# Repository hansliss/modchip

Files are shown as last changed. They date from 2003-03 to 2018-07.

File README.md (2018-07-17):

# modchip
This a PCB design and ASM code for a Playstation modchip based on the tiny AVR AT90S1200.

Apart from the SSOP-20 chip, it uses two MicroMatch connectors (6-pin and 8-pin straight male through-hole mount), a Murata resonator, a LED, a capacitor and a pushbutton.

Note that everything except the MicroMatch connectors are mounted on the *rear* side!

The code wasn't properly version-tracked when I did this, so there are several different ASM files, of different age and for different uses. Figure it out!

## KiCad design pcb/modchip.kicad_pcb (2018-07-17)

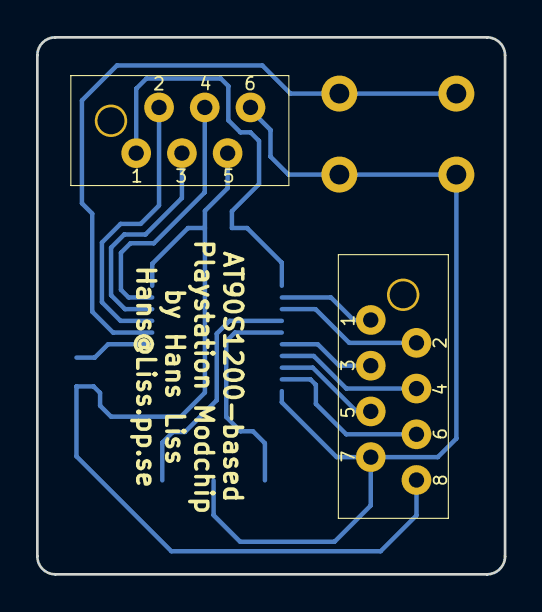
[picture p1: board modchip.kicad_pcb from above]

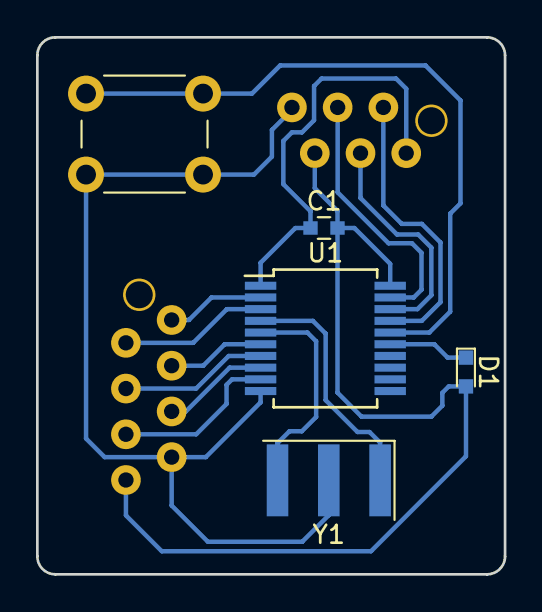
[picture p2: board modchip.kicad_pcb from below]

Board: 2 copper layers, 26.0 x 29.8 mm, 7 parts (5 on the bottom side), 16 nets.

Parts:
C1: C; C_0603
D1: LED; LED_0603
J1: Conn_02x04_Odd_Even; MicroMatch_FOB_TH_08P
J2: Conn_02x03_Odd_Even; MicroMatch_FOB_TH_06P
SW1: SW_Push; SW_PUSH_6mm
U1: AT90S1200-4YC; SSOP-20_5.3x7.2mm_Pitch0.65mm
Y1: Resonator; Resonator_SMD_muRata_SFECV-3pin_6.9x2.9mm

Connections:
GND: J1.7, J2.6, SW1.2, U1.10, Y1.2
unnamed: C1.1, J2.1, U1.1
unnamed: D1.1, U1.15
unnamed: J1.1, U1.2
unnamed: J1.2, U1.3
unnamed: J1.3, U1.6
unnamed: J1.4, U1.7
unnamed: J1.5, U1.8
unnamed: J1.6, U1.9
unnamed: J2.2, U1.17
unnamed: J2.3, U1.18
unnamed: J2.4, U1.19
unnamed: SW1.1, U1.16
unnamed: U1.4, Y1.1
unnamed: U1.5, Y1.3
VCC: C1.2, D1.2, J1.8, J2.5, U1.20

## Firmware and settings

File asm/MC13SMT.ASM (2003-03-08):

;***************************************************************************
;* Playstation Import enabler code
;* 
;* File Name            :modchip.asm
;* Title                :Playstation Import enabler code
;* Date                 :99-04-22
;* Version              :1.3
;* Support email        :Hans@Liss.pp.se
;* Target MCU           :AT90S1200
;* Clock type		:2MHz ceramic resonator or equiv.
;*
;* DESCRIPTION
;*
;* This code will send a Playstation region code (four characters - SCEE
;* for Europe, SCEI for Japan and SCEA for the US) as a serial bitstream
;* at about 250bps on an I/O pin, for a short time after RESET. It also
;* acts as a software jumper between two lines, and can handle blanking of
;* another signal. All these signals will go tristate after a certain time
;* to hide the chip. The processor will restart when the lid is opened and
;* closed and when the RESET switch is pressed and released.
;*
;* There is an option of connecting a pair of switches against GND to two
;* pins, and they can then be used to select between three different CNT
;* values, or disable the chip completely. The status of the switches is
;* read every time the sequence is to be started.
;*
;* A three-legged, dual-colour LED can be connected to two of the I/O pins
;* and GND.
;* It will then be used to show what the processor is doing - cycling
;* between colours when the code is being sent, turning green when it's
;* ready, turning red when disabled and yellow during a pending RESET or
;* media change.
;*
;*                       Processor chip layout
;*
;*	                      -----v-----
;*                         1 [|o        |] 20   Vcc
;*              Lid        2 [|         |] 19   
;*              Reset      3 [|         |] 18   
;*                         4 [|         |] 17   
;*                         5 [|         |] 16   Calibrate
;*              Blanking   6 [|         |] 15   LED
;*              Data OUT   7 [|         |] 14   
;*              Jumper IN  8 [|         |] 13   Switch 2
;*              Jumper OUT 9 [|         |] 12   Switch 1
;*              GND       10 [|         |] 11
;*                            -----------
;*
;*
;* This code is inspired by Scott Rider's widely distributed modchip code for
;* the PIC 12C508. The Atmel chip is far better at most of these things - 
;* many more registers and much more orthogonal instruction set along with
;* four times the speed of a comparable PIC. The AT90S1200 is, however, more
;* expensive than the 12C508, but OTOH it has lots more I/O pins,
;* making all these bells and whistles possible. And programming it is fun!
;* I am working with Atmels own "wavrasm" which as far as I know is 
;* available on their home page on <http://www.atmel.com>.
;*
;* Going back to Scott Rider, we can define a mapping between the pin
;* connections for his code, which appears to be the same for most of the
;* commercially available chips. Pin 1 on the PIC is Vdd, 0-7V, and pin 8 is
;* GND. Pin 5 is used for the "blanking" signal, to block the real data from
;* the CD unit. Pin 6 is the serial data stream.
;* This means that going from a 12C508 to a AT90S1200 gives the following mapping:
;*
;*    From pin    To pin
;*           1 -> 20
;*           5 -> 6
;*           6 -> 7
;*           8 -> 10
;*
;* This code was made for a modern PU-22 motherboard, which is handled
;* somewhat differently. Instead of pin 5 on the 12C508, here we usually have
;* a jumper cable between two positions on the board. In this solution,
;* the LEFT one of these points should be connected to "Jumper IN", and
;* the RIGHT one to "Jumper OUT".
;* You can leave the jumper in there but then the chip can never be
;* completely hidden, which may or may not be significant.
;*
;* Where to find the RESET and Lid signals on an old motherboard is left as
;* an excercise for the reader. All I know is that the Lid signal was usually
;* pin 4 on the older, 18 pin 16c84 modchips.
;*
;* More info and pictures can be found on <http://www.maxking.com>.
;* On the PU-22 board, the CD Lid signal is the one close to the CD connector,
;* and the RESET signal can be found on the upper half of the board.
;*
;* ********* *NEW for version 1.1 ***************
;* I have cleaned up the delay sections and created a single delay function,
;* together with a matching macro, WAITMS. Now the chip will read its delay
;* constants from the EEPROM making it tunable to different chip speeds.
;* There is also a subroutine "calibrate" that can be used to calibrate the
;* delay loop. Connect a pushbutton between earth and pin 19 on the chip. Keep
;* this pressed when starting the Playstation and keep it pressed for exactly
;* 10 seconds, then release it. The new delay constants will be calculated
;* and stored into the EEPROM.
;*
;* ********* *NEW for version 1.2 ***************
;* I have remade some of the Count handling. There are still three different
;* Count values available, selectable with the switch. Now, however, it is
;* possible to change those values. To _decrease_ the current count value,
;* simply boot a game and press the Calibrate button whenever you think
;* that enough pulses have passed, usually just after the copyright screen
;* has disappeared and turned black. To _increase_ the value, wait until the
;* end of the cycle and then press the button. The current Count will increase
;* by ten.
;* There is now also a way to easily recalibrate the speed with a default value
;* for 5V. Just do a normal calibration but release the button almost immediately,
;* and the calibration values will be set to 115 and 103, respectively (my
;* calculated values).
;*
;* ********* *NEW for version 1.2.1 ***************
;* Added debounce to lid and RESET switches. Added weak pullup to RESET input
;*
;* ********* *NEW for version 1.3   ***************
;* The default timing is now calibrated for an AT90S1200 with a 2MHz ceramic
;* resonator, and the default Count value is calibrated for Final Fantasy VIII,
;* which works just fine with this code. All the features are still there but
;* they are mostly unnecessary now..
;*
;***************************************************************************


.device	AT90S1200	;Prohibits use of non-implemented instructions

.include "1200def.inc"

.LISTMAC

;***** Global Register Variables


;***** Arg registers
.def	A1	=r16
.def	A2	=r17
.def	A3	=r18
.def	CNT	=r19
.def	D1	=r28
.def	D2	=r29
.def	X	=r30
.def	curC	=r23

;***** Scratch regs
.def	I	=r20
.def	J	=r21
.def	K	=r22

;***** EEPROM vars
.equ	storedD1=0
.equ	storedD2=1
.equ	storedC1=2
.equ	storedC2=3
.equ	storedC3=4

;.equ	defaultD1=115
;.equ	defaultD2=103
.equ	defaultD1=$FE
.equ	defaultD2=$FD
.equ	defaultC=100

;******* PORT B

;  Switches - active low: 0=off, 1=Use COUNT1, 2=Use COUNT2, 3=Use COUNT3
.equ	SWITCH1=0
.equ	SWITCH2=1

.equ	SWITCH3=4

;  Red and green LED ouput pins
.equ	LEDBIT=3
;.equ	GLEDBIT=6

;******* PORT D

;  Media change signal, active high input
.equ	LSIG=0
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

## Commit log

2003-03-08 Initial Import
    [MC12.OBJ, MC12SMT.OBJ, MC13SMT.OBJ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]
2018-07-17 Removed binary files and log files
    [MC12.OBJ, MC12SMT.OBJ, MC13SMT.OBJ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]
2018-07-17 Added KiCAD design and README
    [modchip.kicad_pcb, modchip.sch]
2018-07-17 Added Gerber plot files
    [modchip-B.CrtYd.gbr, modchip-B.Cu.gbr, modchip-B.Fab.gbr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]
